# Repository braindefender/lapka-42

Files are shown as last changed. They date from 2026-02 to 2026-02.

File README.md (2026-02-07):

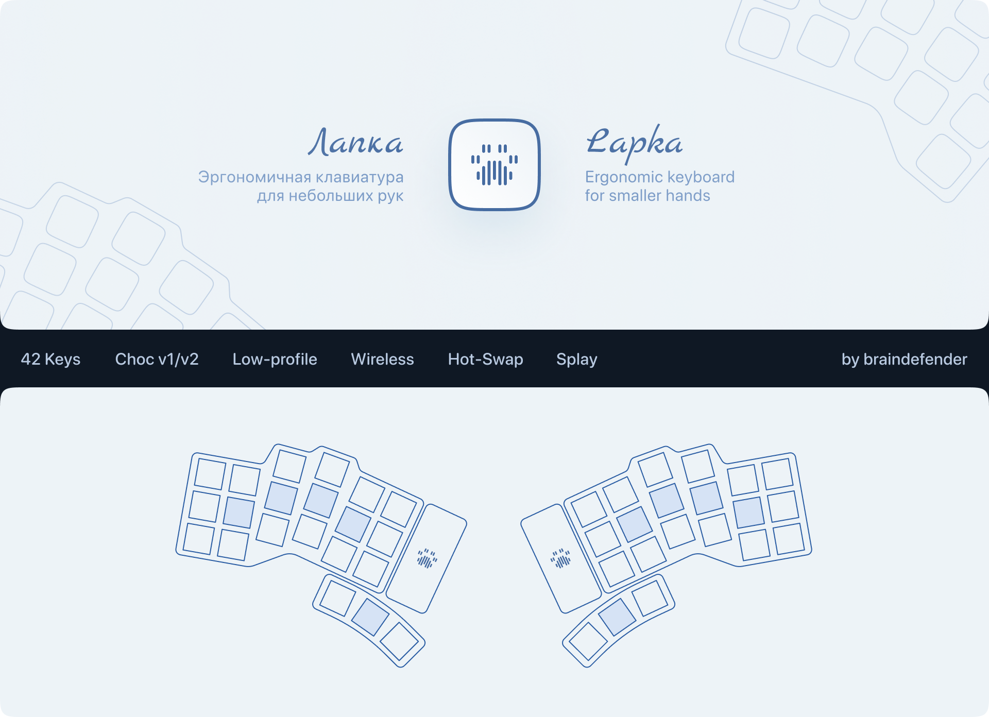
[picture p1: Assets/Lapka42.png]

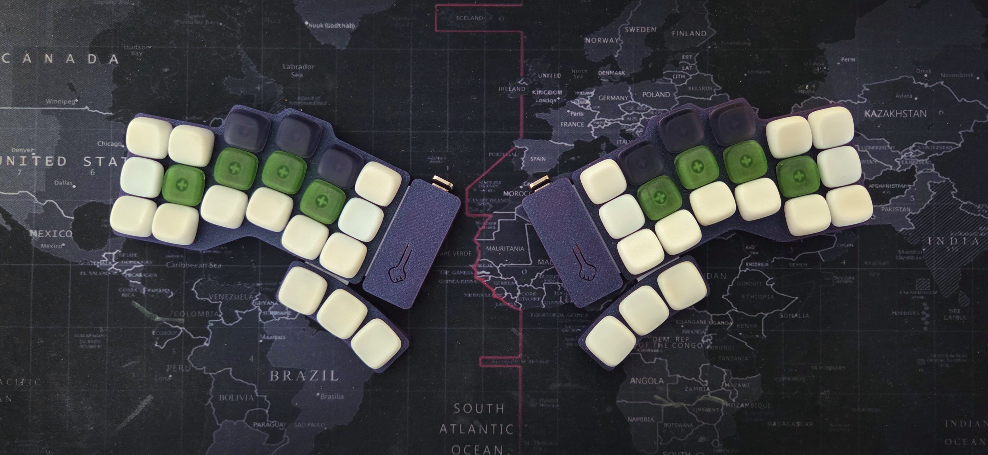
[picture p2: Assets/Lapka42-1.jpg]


[English version of this README](./README_EN.md)

# Лапка 42

Беспроводная эргономичная сплит-клавитура для тех, у кого лапки (:

**Информация:**

| | |
| :--- | :--- |
| **Количество клавиш** | 42 |
| **Тип матрицы** | Диодная |
| **Направление диодов**  | Col2Row |
| **Совместимые MCU** | nRF52840 (SuperMini, nice!nano) |
| **Совместимые АКБ** | 401230 |
| **Совместимые свитчи**  | Choc v1/v2 |
| **Свитч-спейсинг** | Choc (18×17mm) |
| **Расположение клавиш** | Splay |

**Структура репозитория:**

| Директория | Описание |
| ---: | :--- |
| 3MF | Проект OrcaSlicer (для примера параметров печати) |
| Assets | Изображения и фото |
| Build | Описание [процесса сборки](./Build/BUILD_GUIDE_RU.md) |
| Fusion | Проект Autodesk Fusion 360 |
| Gerbers | Gerber-файлы для производства плат |
| KiCad | Проект KiCad (схема, плата, компоненты) |
| STL | 3D-модели частей корпуса |

**Части корпуса:**
| Файл | Описание |
| -----: | :--- |
| Bottom | Нижняя часть корпуса, имеет вырезы под hotswap-сокеты и диоды |
|  Cover | Крышка для АКБ и кнопки Reset |
|  Frame | Верхняя часть корпуса, для тайп-кластера |
|  Thumb | Верхняя часть корпуса, для тамб-кластера |

**Разметка пинов:**

> C — колонки, R — строки, нумерация слева направо, сверху вниз

|  Пин  | Левая | Правая |
| :---: | :---: | :----: |
|  C0 |  D4 |  D10 |
|  C1 |  D5 |  D16 |
|  C2 |  D6 |  D14 |
|  C3 |  D7 |  D15 |
|  C4 |  D8 |  D18 |
|  C5 |  D9 |  D19 |
| | |
|  R0 |  D2 |  D21 |
|  R1 |  D3 |  D20 |
|  R2 |  D16  | D8 |
|  R3 |  D10  | D9 |

## Прошивка

- [`ZMK × Wellum`](https://github.com/braindefender/lapka-zmk-config/tree/lapka-42)
- `RMK × Wellum` — *в разработке*

## История изменений

### v1
- Первичный релиз.

## Фото

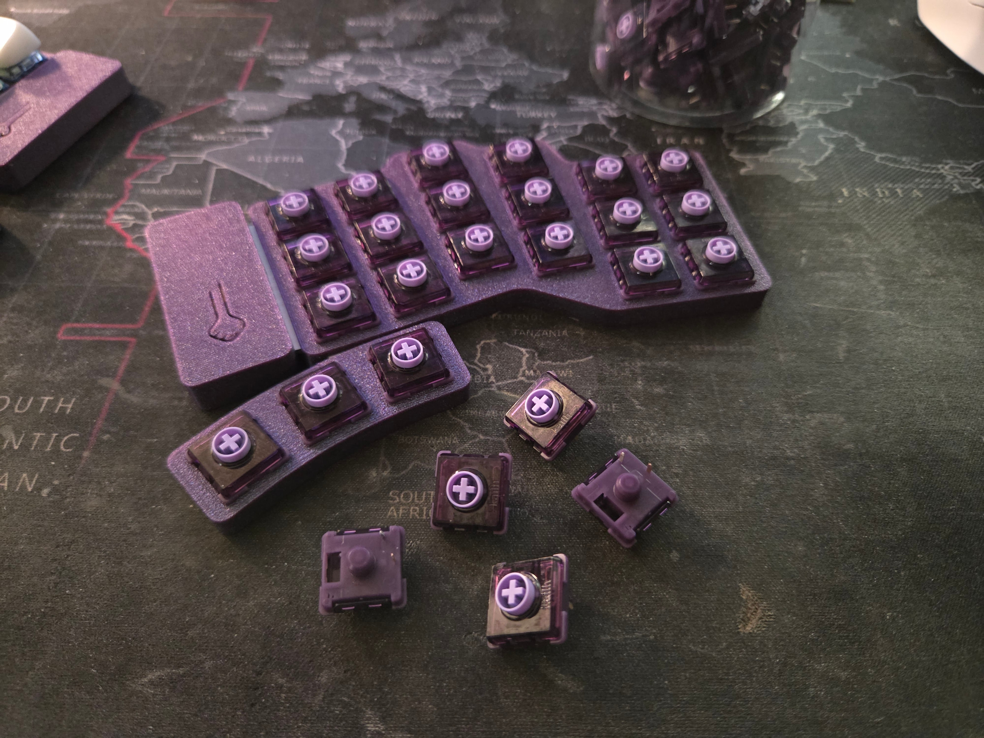
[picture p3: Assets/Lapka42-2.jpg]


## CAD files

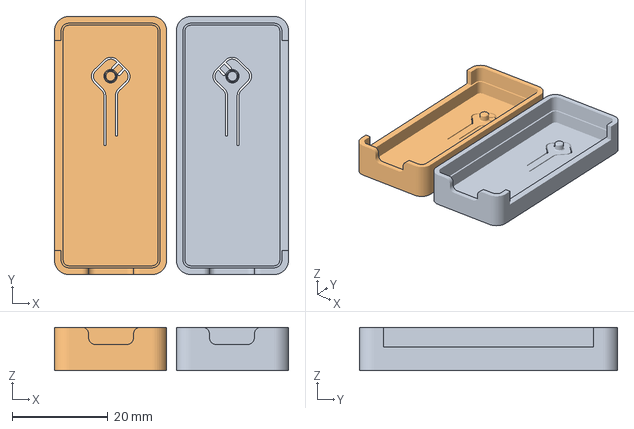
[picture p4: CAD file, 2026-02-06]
3MF/Cover.3mf
49.0 x 54.0 x 9.10 mm
Cover.stl x 2

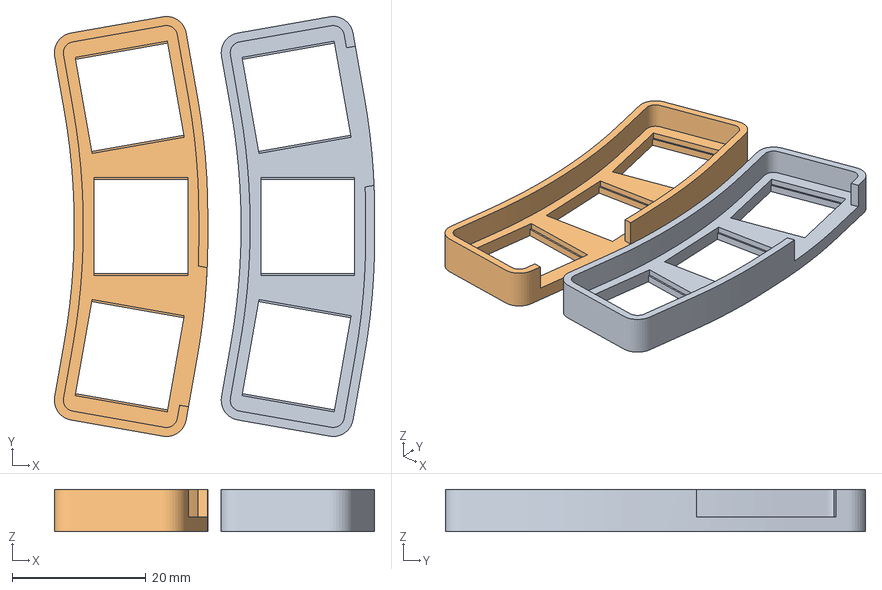
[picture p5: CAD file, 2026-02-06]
3MF/Thumb.3mf
47.9 x 62.9 x 6.30 mm
Thumb.stl x 2

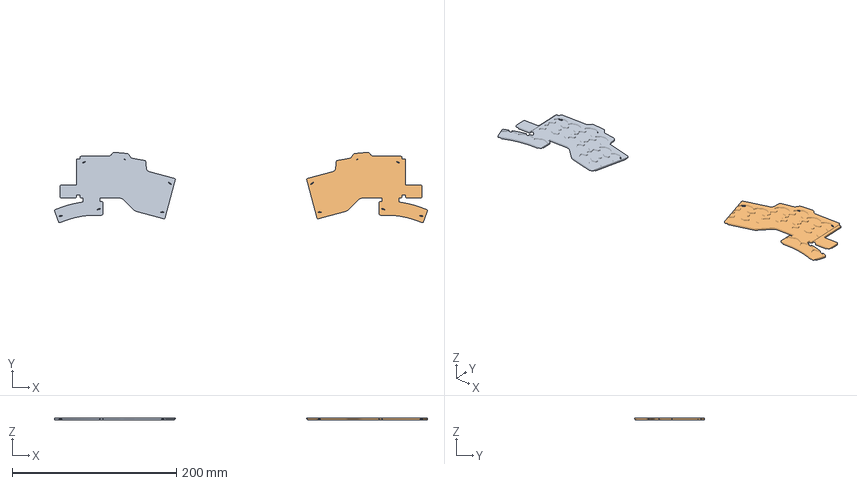
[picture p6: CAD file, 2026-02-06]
3MF/Bottom.3mf
454.4 x 85.7 x 2.30 mm
Bottom.stl x 2

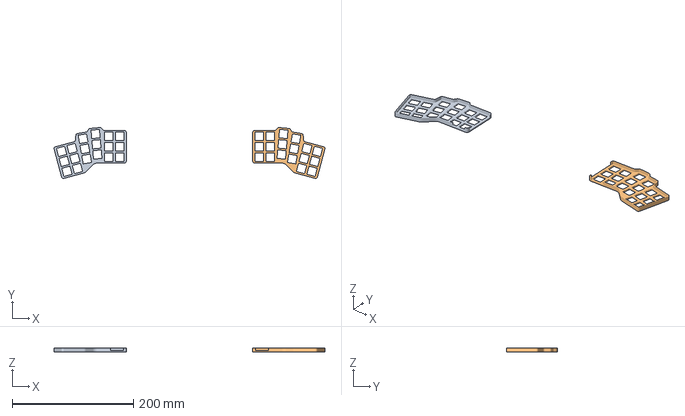
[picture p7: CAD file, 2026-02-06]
3MF/Frame.3mf
447.2 x 84.1 x 6.30 mm
Frame.stl x 2

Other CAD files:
STL/Bottom.stl
STL/Cover.stl
STL/Frame.stl
STL/Thumb.stl

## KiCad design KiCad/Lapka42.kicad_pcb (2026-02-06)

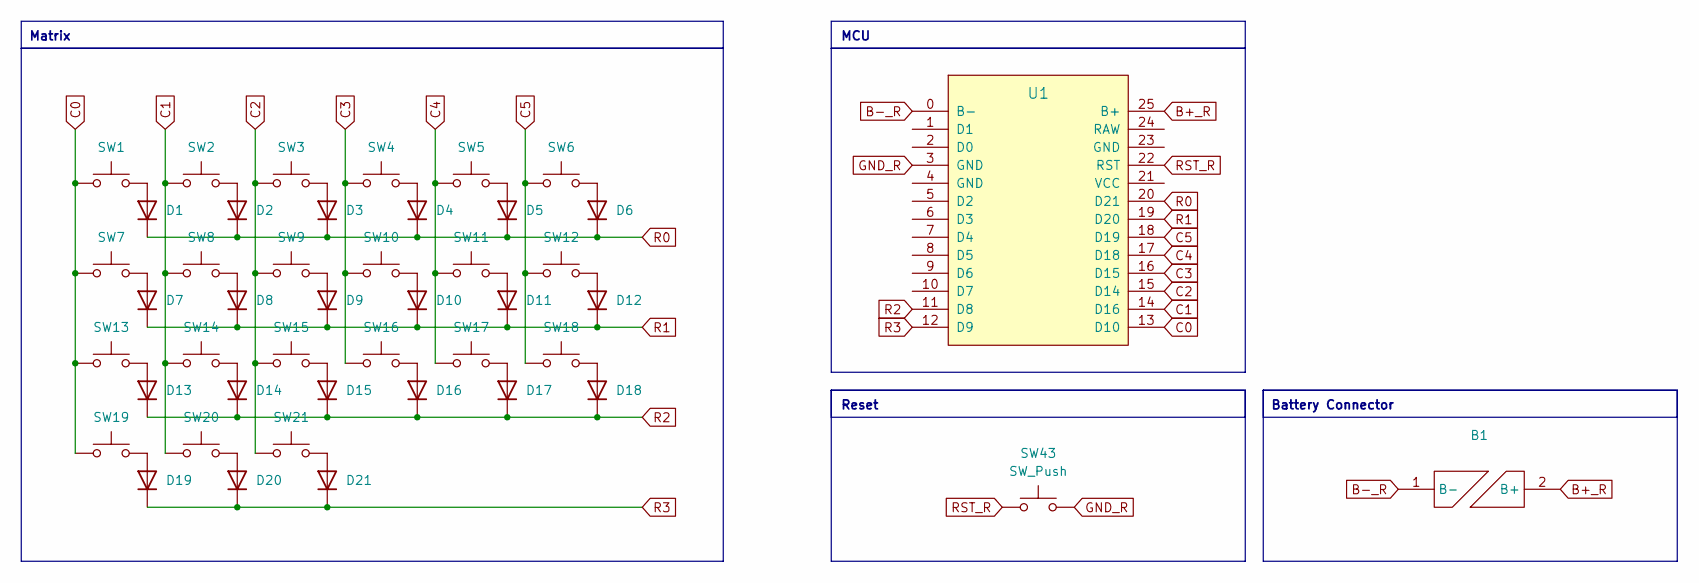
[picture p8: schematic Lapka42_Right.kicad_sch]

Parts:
B1: BAT_RECT
D1, D2, D3, D4, D5, D6, D7, D8, D9, D10, D11, D12, D13, D14, D15, D16, D17, D18, D19, D20, D21: D_SOD-323_Increased
SW1, SW2, SW3, SW4, SW5, SW6, SW7, SW8, SW9, SW10, SW11, SW12, SW13, SW14, SW15, SW16, SW17, SW18, SW19, SW20, SW21: SW_Choc_V1V2_HS
SW43: SW_Push; SW_SMD_5x5
U1: U_ProMicro_nRF52840_MidMount

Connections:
B+_R: B1.2 (B+), U1.25 (B+)
B-_R: B1.1 (B-), U1.0 (B-)
C0: SW1.1, SW7.1, SW13.1, SW19.1, U1.13 (D10)
C1: SW2.1, SW8.1, SW14.1, SW20.1, U1.14 (D16)
C2: SW3.1, SW9.1, SW15.1, SW21.1, U1.15 (D14)
C3: SW4.1, SW10.1, SW16.1, U1.16 (D15)
C4: SW5.1, SW11.1, SW17.1, U1.17 (D18)
C5: SW6.1, SW12.1, SW18.1, U1.18 (D19)
GND_R: SW43.2, U1.3 (GND)
unnamed: D1.2 (A), SW1.2
unnamed: D2.2 (A), SW2.2
unnamed: D3.2 (A), SW3.2
unnamed: D4.2 (A), SW4.2
unnamed: D5.2 (A), SW5.2
unnamed: D6.2 (A), SW6.2
unnamed: D7.2 (A), SW7.2
unnamed: D8.2 (A), SW8.2
unnamed: D9.2 (A), SW9.2
unnamed: D10.2 (A), SW10.2
unnamed: D11.2 (A), SW11.2
unnamed: D12.2 (A), SW12.2
unnamed: D13.2 (A), SW13.2
unnamed: D14.2 (A), SW14.2
unnamed: D15.2 (A), SW15.2
unnamed: D16.2 (A), SW16.2
unnamed: D17.2 (A), SW17.2
unnamed: D18.2 (A), SW18.2
unnamed: D19.2 (A), SW19.2
unnamed: D20.2 (A), SW20.2
unnamed: D21.2 (A), SW21.2
R0: D1.1 (K), D2.1 (K), D3.1 (K), D4.1 (K), D5.1 (K), D6.1 (K), U1.20 (D21)
R1: D7.1 (K), D8.1 (K), D9.1 (K), D10.1 (K), D11.1 (K), D12.1 (K), U1.19 (D20)
R2: D13.1 (K), D14.1 (K), D15.1 (K), D16.1 (K), D17.1 (K), D18.1 (K), U1.11 (D8)
R3: D19.1 (K), D20.1 (K), D21.1 (K), U1.12 (D9)
RST_R: SW43.1, U1.22 (RST)

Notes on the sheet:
Battery Connector
MCU
Matrix
Reset

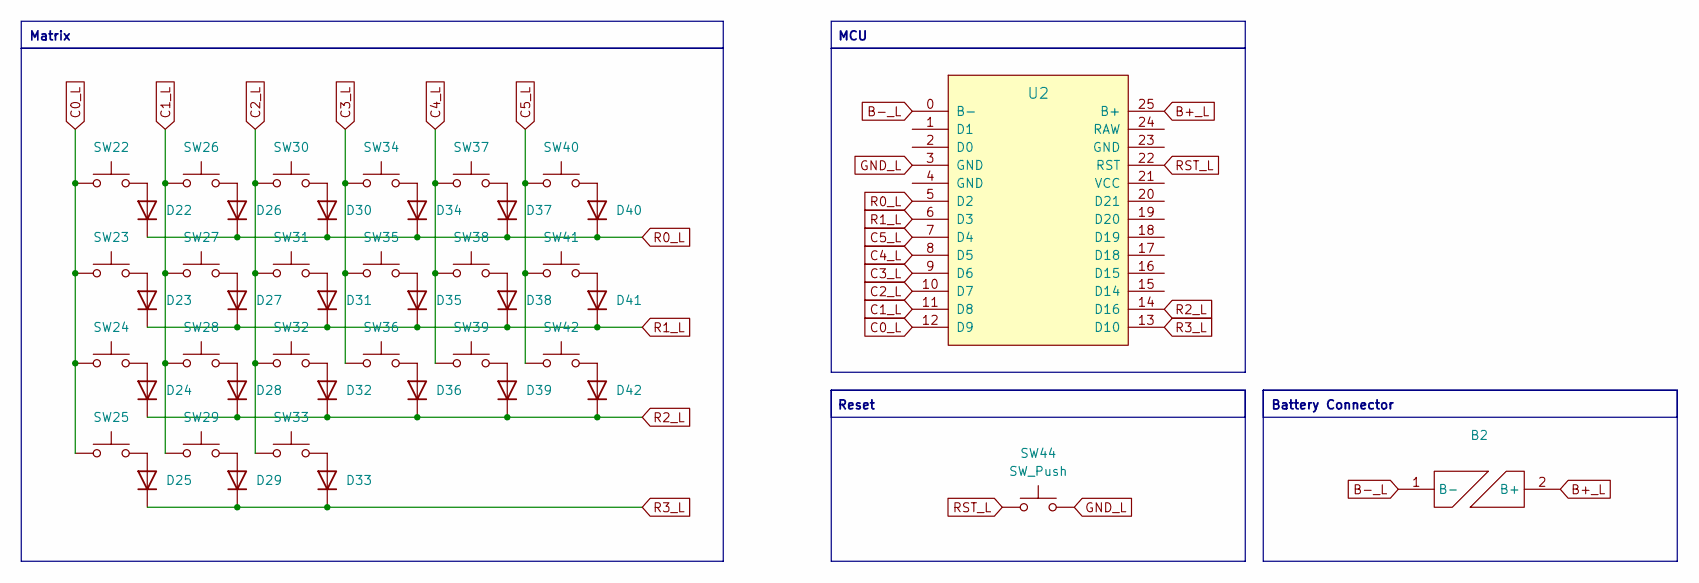
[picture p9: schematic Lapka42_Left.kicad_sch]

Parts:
B2: BAT_RECT
D22, D23, D24, D25, D26, D27, D28, D29, D30, D31, D32, D33, D34, D35, D36, D37, D38, D39, D40, D41, D42: D_SOD-323_Increased
SW22, SW23, SW24, SW25, SW26, SW27, SW28, SW29, SW30, SW31, SW32, SW33, SW34, SW35, SW36, SW37, SW38, SW39, SW40, SW41, SW42: SW_Choc_V1V2_HS
SW44: SW_Push; SW_SMD_5x5
U2: U_ProMicro_nRF52840_MidMount

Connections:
B+_L: B2.2 (B+), U2.25 (B+)
B-_L: B2.1 (B-), U2.0 (B-)
C0_L: SW22.1, SW23.1, SW24.1, SW25.1, U2.12 (D9)
C1_L: SW26.1, SW27.1, SW28.1, SW29.1, U2.11 (D8)
C2_L: SW30.1, SW31.1, SW32.1, SW33.1, U2.10 (D7)
C3_L: SW34.1, SW35.1, SW36.1, U2.9 (D6)
C4_L: SW37.1, SW38.1, SW39.1, U2.8 (D5)
C5_L: SW40.1, SW41.1, SW42.1, U2.7 (D4)
GND_L: SW44.2, U2.3 (GND)
unnamed: D22.2 (A), SW22.2
unnamed: D23.2 (A), SW23.2
unnamed: D24.2 (A), SW24.2
unnamed: D25.2 (A), SW25.2
unnamed: D26.2 (A), SW26.2
unnamed: D27.2 (A), SW27.2
unnamed: D28.2 (A), SW28.2
unnamed: D29.2 (A), SW29.2
unnamed: D30.2 (A), SW30.2
unnamed: D31.2 (A), SW31.2
unnamed: D32.2 (A), SW32.2
unnamed: D33.2 (A), SW33.2
unnamed: D34.2 (A), SW34.2
unnamed: D35.2 (A), SW35.2
unnamed: D36.2 (A), SW36.2
unnamed: D37.2 (A), SW37.2
unnamed: D38.2 (A), SW38.2
unnamed: D39.2 (A), SW39.2
unnamed: D40.2 (A), SW40.2
unnamed: D41.2 (A), SW41.2
unnamed: D42.2 (A), SW42.2
R0_L: D22.1 (K), D26.1 (K), D30.1 (K), D34.1 (K), D37.1 (K), D40.1 (K), U2.5 (D2)
R1_L: D23.1 (K), D27.1 (K), D31.1 (K), D35.1 (K), D38.1 (K), D41.1 (K), U2.6 (D3)
R2_L: D24.1 (K), D28.1 (K), D32.1 (K), D36.1 (K), D39.1 (K), D42.1 (K), U2.14 (D16)
R3_L: D25.1 (K), D29.1 (K), D33.1 (K), U2.13 (D10)
RST_L: SW44.1, U2.22 (RST)

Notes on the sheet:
Reset
Matrix
Battery Connector
MCU

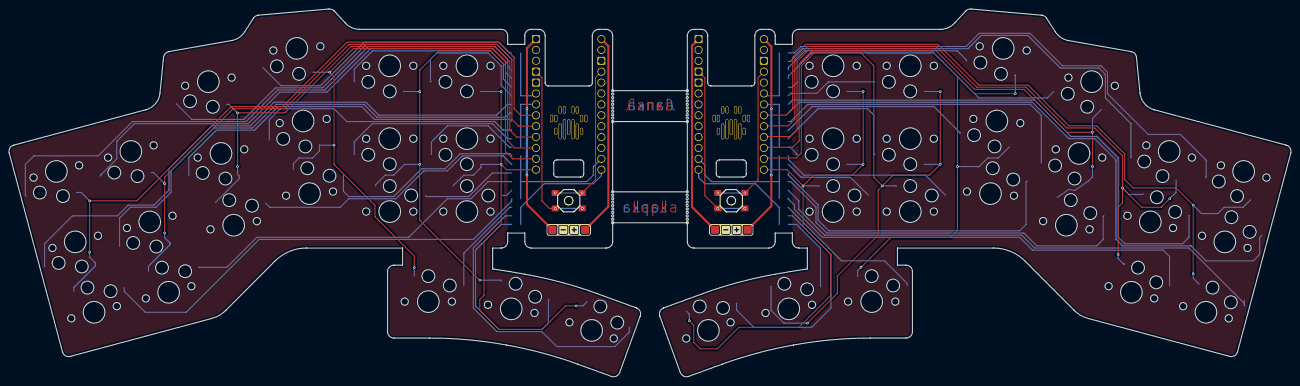
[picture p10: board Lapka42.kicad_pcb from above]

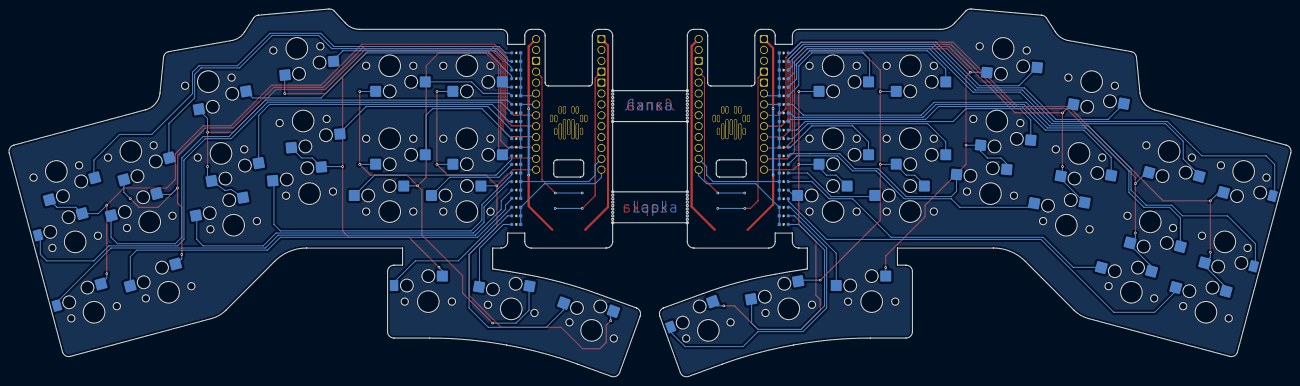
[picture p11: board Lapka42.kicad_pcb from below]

Board: 2 copper layers, 299.0 x 85.8 mm, 90 parts (42 on the bottom side), 70 nets.

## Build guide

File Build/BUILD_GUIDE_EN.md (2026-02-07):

# Build guide

## List of required parts

| Part | Amount | Description | Link |
| --- | --- | --- | --- |
| PCB | 2 | Main PCB board | |
| MCU | 2 | nRF52840 MCU | [Link](#nrf52840-mcu) |
| Battery | 2 | 401230 Size, 120-150mAh | [Link](#401230-battery) |
| Tactile button  | 2 | 4x4x1.5mm button | [Link](#tactile-button) |
| SMD Diode | 42 | 1N4148 (SOD-323) | [Link](#1n4148-sod-323-diode) |
| Hot-Swap socket | 42 | Kailh PG1350 | [Link](#kailh-pg1350-hot-swap-socket) |
| Switches | 42 | Kailh Choc v1 / v2 | [Link](#kailh-choc-v1--v2) |
| Keycaps | 42 | Choc-Spacing | [Link](#choc-spacing-keycaps) |
| Pin Header | 9×2×2  | (Optional) | [Link](#hot-swap-pin-header) |
| Rubber feet | 16 | 8x2mm | [Link](#rubber-feet) |

| Name | Amount | Description |
| --- | --- | --- |
| `Frame_Main`  | 2 | Type-cluster case |
| `Frame_Thumb` | 2 | Thumb-cluster case |
| `Cover` | 2 | Battery/Reset cover |
| `Bottom` | 2 | Bottom part of the case |

## Parts Links

### 401230 Battery
You can buy these in most places. These batteries are widely used in portable devices.
Don't be fooled by the large declared capacity (200-250+), often it's only 120-150mAh.

- [OZON | MyDigitals](https://www.ozon.ru/product/akkumulyator-batareya-401230-120mah-3-7v-30h12h4-mm-1812801020/)
- [AliExpress | EasyLander](https://aliexpress.ru/item/1005006119986947.html?sku_id=12000048850576528)

### nRF52840 MCU
> Notice the USB-C connector [difference](#mcu-usb-c-difference)

- [AliExpress | TENSTAR Store](https://aliexpress.ru/item/1005006282506884.html)
- [AliExpress | Simple Robot Store](https://aliexpress.ru/item/1005008896713501.html)

### Hot-Swap Pin Header
This is completely optional. You can solder MCU to PCB with those that come with MCU.
However, using Hot-Swap Pin Headers is more convinient even if you won't use hot-swap.

- [AliExpress | EQV Official Store](https://aliexpress.ru/item/1005007465756012.html)

### 1N4148 SOD-323 Diode
- [AliExpress | TZT teng Official Store](https://aliexpress.ru/item/1005008443360532.html)

### Tactile Button
- [AliExpress | LOSUYINE Store](https://aliexpress.ru/item/32815925814.html)
- [AliExpress | KRYOND Electronic Store](https://aliexpress.ru/item/1005009981759314.html)

### Rubber Feet
- [AliExpress | Meifang Store](https://aliexpress.ru/item/1005005315398342.html)

### Kailh PG1350 Hot-Swap Socket
- [AliExpress | Dafu Store](https://aliexpress.ru/item/1005009449387695.html)
- [AliExpress | KBDiy Switch Store](https://aliexpress.ru/item/1005004916925259.html)

### Kailh Choc v1 / v2
I highly recommend checking out [Watchman's Switch Database](https://aroum.github.io)

### Choc-Spacing Keycaps
> Currently, there are almost no keycaps for Choc v2 with Choc spacing on the market. Of the open-source options, I can only suggest [KLP Lamé](https://github.com/braindefender/KLP-Lame-Keycaps).

- [GitHub | KLP Lamé](https://github.com/braindefender/KLP-Lame-Keycaps)
- [GitHub | GammaCaps](https://github.com/sqdbruh/gammacaps)
- [BeeKeeb | Tai-Hao THCS](https://showcase.beekeeb.com/choc-spaced-chocv2-keycaps/)

## Guide

1. Make sure you have all the necessary parts for assembly, as well as a soldering iron, solder paste, or solder wire (soldering paste will be much easier).

2. Separate the boards from the shipping connectors. This can be done by gently breaking them off, holding them with your fingers near the break seam.

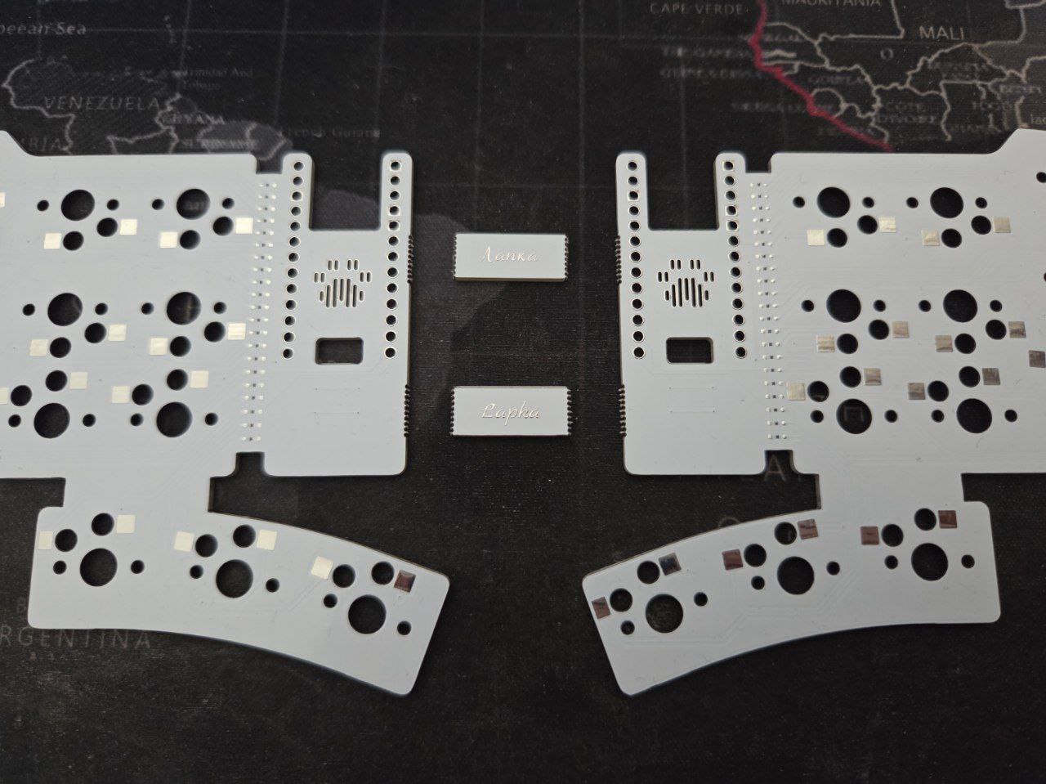
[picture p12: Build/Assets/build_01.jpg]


3. Apply solder paste to the hotswap socket pads and solder the sockets. The socket should be positioned so that the larger part faces out to the side and the smaller part faces the center.

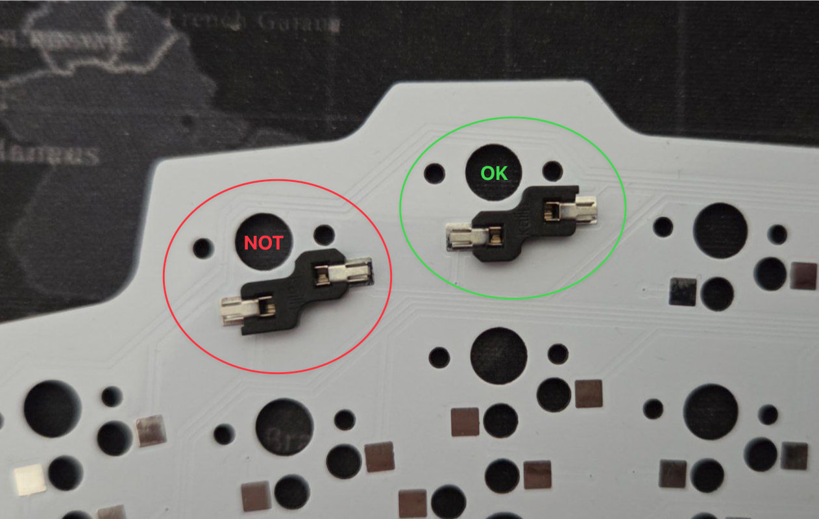
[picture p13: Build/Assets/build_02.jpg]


> I usually apply solder paste to all the socket pads, then install the sockets and solder one right pin of each socket (from right to left) first, holding the socket with my finger. After that, I rotate the board 180° and repeat the same process for the left pin of the socket. This allows me to solder all the sockets quickly and without misalignment.

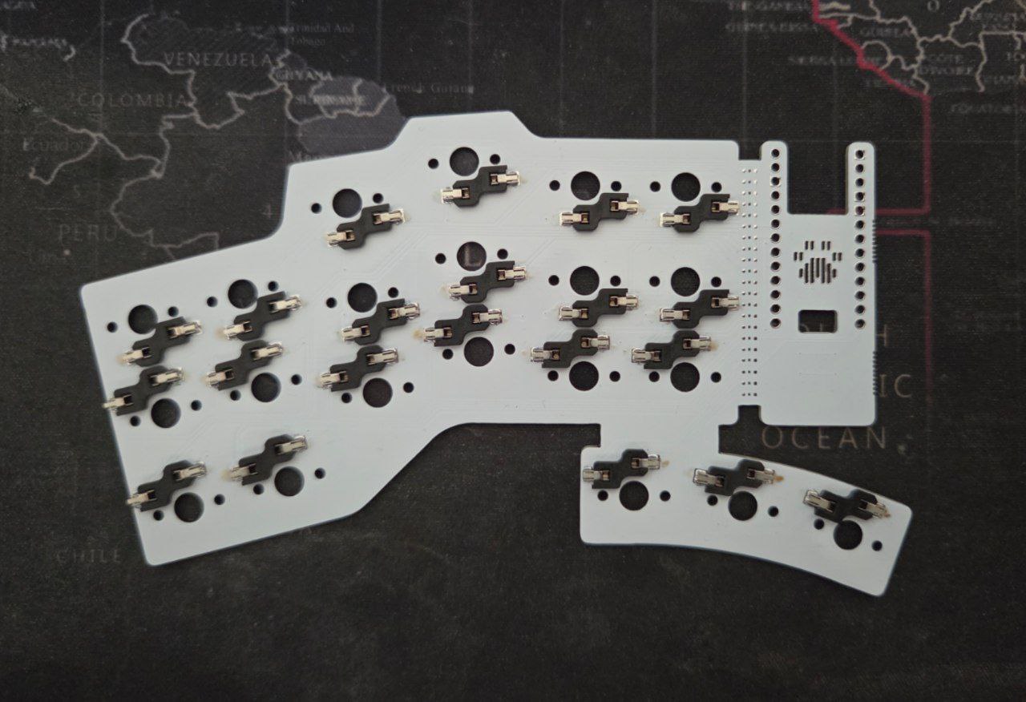
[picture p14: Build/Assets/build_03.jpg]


4. Apply solder paste to the pads for the SMD diodes and solder the diodes themselves. The diodes should be positioned according to the [markings](#1n4148w-t4-diode-markings). Two stripes on the diode body indicate the position of the **cathode** — so we position the diodes so that these two stripes face the controller.

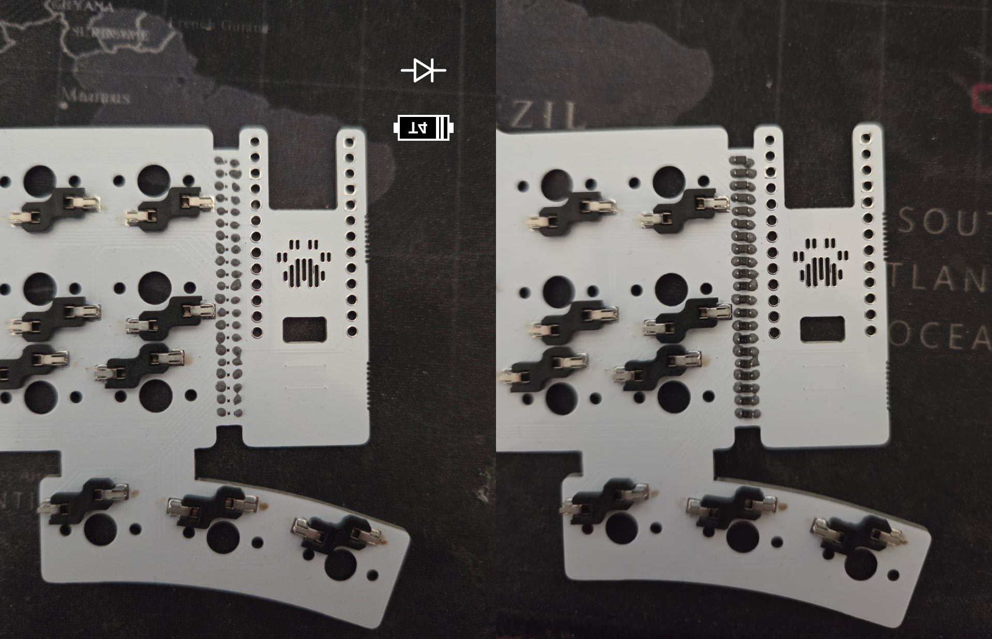
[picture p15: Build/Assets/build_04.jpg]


5. Prepare the pin headers. To measure how much to break it, push the pins into the holes on either side of the board. You should have exactly 9 pins. We'll need two of these pieces.

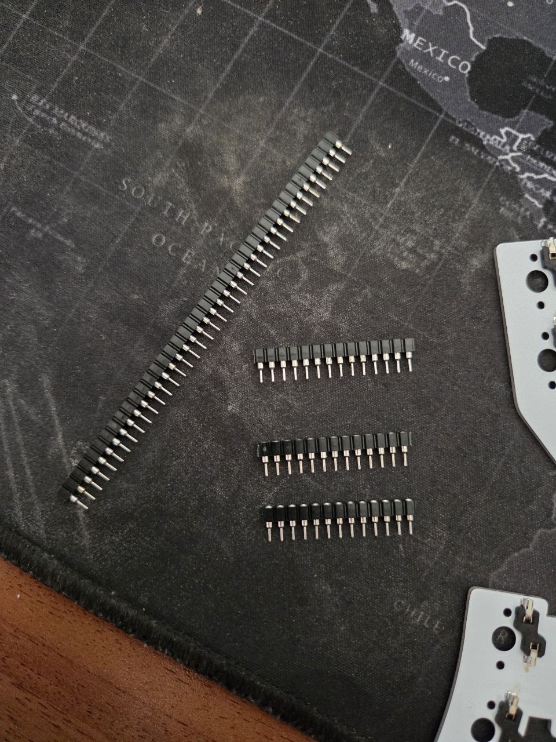
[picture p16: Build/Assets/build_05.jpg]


6. Apply solder paste to the pin header holes and install the pin header in the holes so that the plastic part is on the opposite side from the diodes/sockets. You can solder the outer pins to keep it in place. During soldering, any solder paste remaining on the pins will naturally move down to the pad.

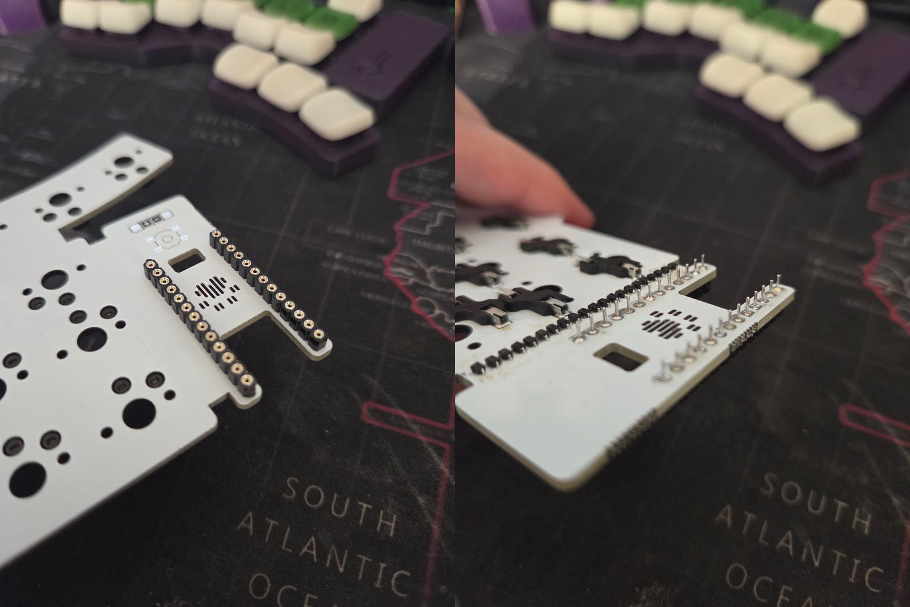
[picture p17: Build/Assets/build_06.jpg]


7. After the hotswap sockets, diodes, and pin headers have been soldered, thoroughly clean the board of flux. I do this with isopropyl alcohol, wiping the pads with a toothbrush or a stiff brush. After cleaning, leave the board in a warm place to allow all the alcohol or water to dry. While one board is drying, you can begin soldering the other half.

8. Make sure the nRF52840 controllers are working properly. To do this, you can flash a [test firmware](https://github.com/braindefender/lapka-zmk-config/tree/lapka-42-test), short the row and column contacts in pairs, and observe how the keys are pressed using [key-test](https://key-test.ru). Or, you can skip this step at your own risk. However, desoldering a faulty controller is the last thing you want to do, so it's better to be safe than sorry.

9. Install the nRF52840 controller on the pins with the SMD components facing the board. There are cutouts on the board for the antenna, USB Type-C connector, and a couple of (transistors?). After installing the controller, apply solder paste to the contacts and solder it. Be careful to hold the controller level when soldering, otherwise one side will stick out beyond the case.

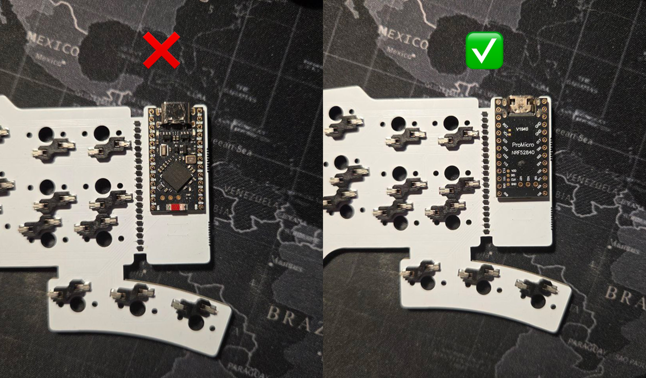
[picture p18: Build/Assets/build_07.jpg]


10. Apply solder paste to the tactile button and battery pads and solder them in place. The black wire is the minus, and the red wire is plus. The tactile button also has polarity — position it horizontally.

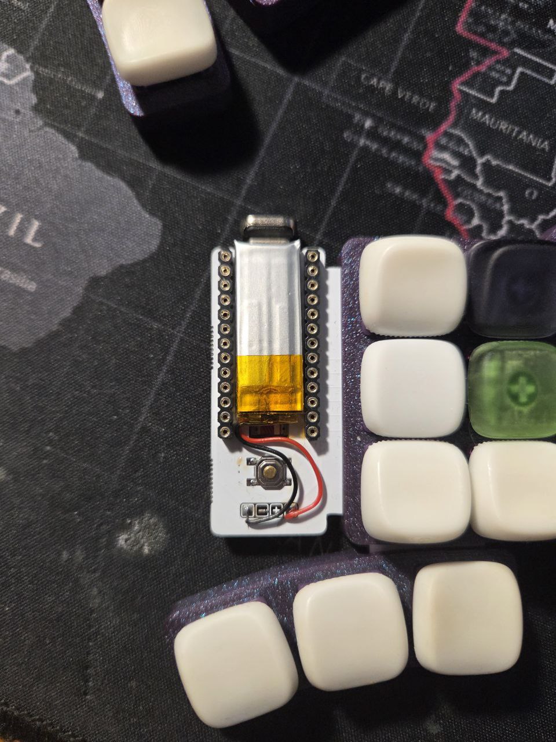
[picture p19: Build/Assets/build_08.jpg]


11. Once all the components are soldered, you can install the case parts and insert the switches into the sockets. Done! Now you can [flash the keyboard](../README_EN.md#firmware) and use it.

## Notes

### MCU USB-C Difference

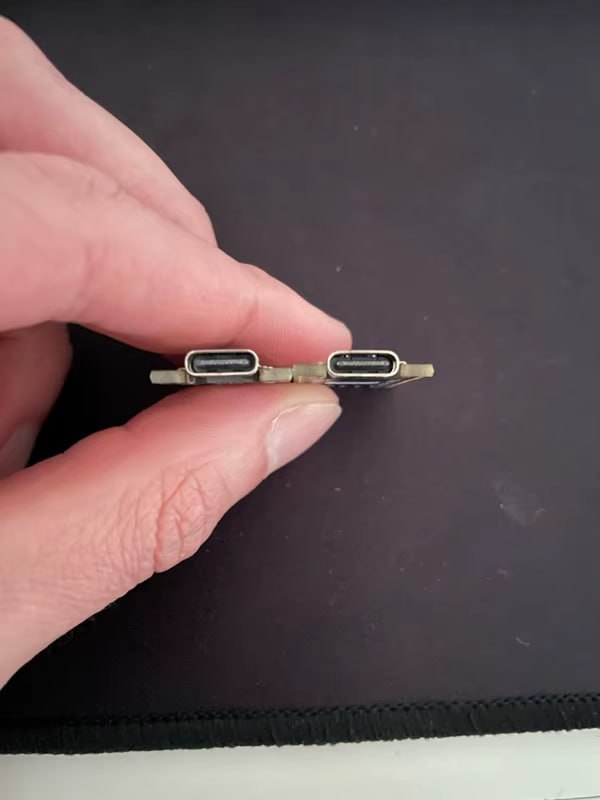
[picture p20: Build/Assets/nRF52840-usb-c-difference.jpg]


[nRF52840](https://github.com/joric/nrfmicro/wiki/Alternatives#supermini-nrf52840) is sold in several variants, among which there is a difference in the USB Type-C connector. For example, boards from Simple Robot Store have an extended USB-C port, while most boards from other vendors/manufacturers have a standard USB-C port. The MCU enclosure supports both types.

### 1N4148W (T4) Diode markings

Cathode is marked with one or several stripes on the diode body.

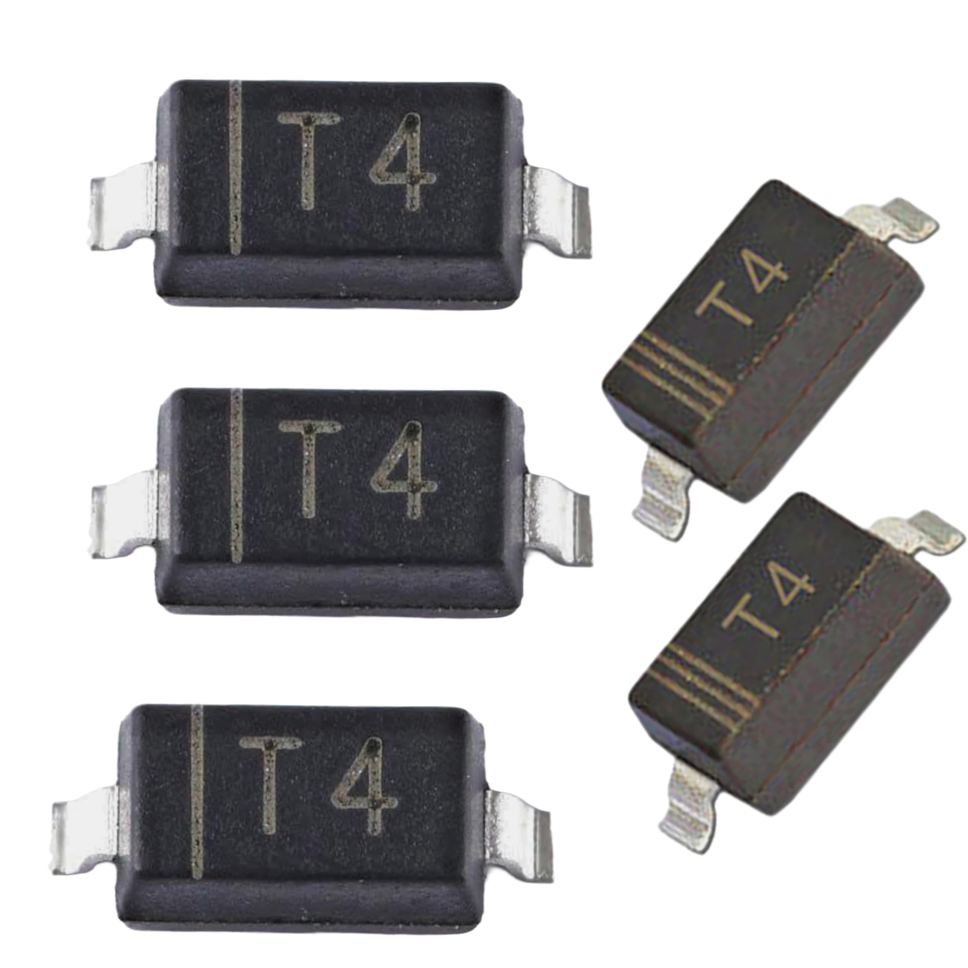
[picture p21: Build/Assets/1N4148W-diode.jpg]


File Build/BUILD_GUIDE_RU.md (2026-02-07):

# Инструкция по сборке

## Список необходимых деталей

| Деталь | Кол-во | Описание | Ссылка |
| --- | --- | --- | --- |
| PCB | 2 | Основная плата | |
| MCU | 2 | Контроллер nRF52840 | [Ссылка](#nrf52840-mcu) |
| Батарея | 2 | Размер 401230, 120-150mAh | [Ссылка](#401230-battery) |
| Тактовая кнопка | 2 | 4x4x1.5mm button | [Ссылка](#tactile-button) |
| SMD Диоды | 42 | 1N4148 (SOD-323) | [Ссылка](#1n4148-sod-323-diode) |
| Hot-Swap сокеты | 42 | Kailh PG1350 | [Ссылка](#kailh-pg1350-hot-swap-socket) |
| Свитчи | 42 | Kailh Choc v1 / v2 | [Ссылка](#kailh-choc-v1--v2) |
| Кейкапы | 42 | Choc-Spacing | [Ссылка](#choc-spacing-keycaps) |
| Гребёнка | 9×2×2  | (Опционально) | [Ссылка](#hot-swap-pin-header) |
| Силиконовые бамперы | 16 | 8x2mm | [Ссылка](#силиконовые-бамперы) |

| Название | Кол-во | Описание |
| --- | --- | --- |
| `Frame_Main`  | 2 | Корпус для тайп-кластера  |
| `Frame_Thumb` | 2 | Корпус для тамб-кластера  |
| `Cover` | 2 | Крышка для батареи/ресета |
| `Bottom` | 2 | Нижняя часть корпуса |

## Ссылки на детали

### 401230 Battery
Можно купить практически где угодно. На OZON их куча. Такие АКБ стоят в видео-регистраторах.
Не ведитесь на большую заявленную ёмкость (200-250+), зачастую там всего 120-150mAh.

- [OZON | MyDigitals](https://www.ozon.ru/product/akkumulyator-batareya-401230-120mah-3-7v-30h12h4-mm-1812801020/)
- [AliExpress | EasyLander](https://aliexpress.ru/item/1005006119986947.html?sku_id=12000048850576528)

### nRF52840 MCU
> Стоит обратить внимание на [отличия коннектора USB-C](#разница-mcu-usb-c)

- [AliExpress | TENSTAR Store](https://aliexpress.ru/item/1005006282506884.html)
- [AliExpress | Simple Robot Store](https://aliexpress.ru/item/1005008896713501.html)

### Hot-Swap Pin Header
Это полностью опционально. Вы можете припаять контроллер к плате с помощью комплектной гребёнки.
Однако hot-swap гребёнку паять будет удобнее, даже если вы не планируете использовать hot-swap.

- [AliExpress | EQV Official Store](https://aliexpress.ru/item/1005007465756012.html)

### 1N4148 SOD-323 Diode
- [AliExpress | TZT teng Official Store](https://aliexpress.ru/item/1005008443360532.html)

### Tactile Button
- [AliExpress | LOSUYINE Store](https://aliexpress.ru/item/32815925814.html)
- [AliExpress | KRYOND Electronic Store](https://aliexpress.ru/item/1005009981759314.html)

### Силиконовые бамперы
- [AliExpress | Meifang Store](https://aliexpress.ru/item/1005005315398342.html)

### Kailh PG1350 Hot-Swap Socket
- [AliExpress | Dafu Store](https://aliexpress.ru/item/1005009449387695.html)
- [AliExpress | KBDiy Switch Store](https://aliexpress.ru/item/1005004916925259.html)

### Kailh Choc v1 / v2
Настоятельно рекомендую изучить [базу свитчей от Watchman'а](https://aroum.github.io)

### Choc-Spacing Keycaps
> На данный момент, на рынке очень мало кейкапов для Choc v2 с Choc-спейсингом. Из open-source вариантов, я могу предложить только [KLP Lamé](https://github.com/braindefender/KLP-Lame-Keycaps).

- [GitHub | KLP Lamé](https://github.com/braindefender/KLP-Lame-Keycaps)
- [GitHub | GammaCaps](https://github.com/sqdbruh/gammacaps)
- [BeeKeeb | Tai-Hao THCS](https://showcase.beekeeb.com/choc-spaced-chocv2-keycaps/)

## Инструкция

1. Проверьте, что у вас имеются все необходимые детали для сборки, а также паяльник, паяльная паста или припой (с паяльной пастой будет значительно удобнее).

2. Отделите платы от транспортировочных перемычек. Это можно сделать просто аккуратно отломив их, придерживая пальцами недалеко от места излома.



3. Нанесите паяльную пасту на площадки для hotswap-сокетов и припаяйте сами сокеты. Сокет нужно располагать так, чтобы его большая часть смотрела в сторону, а маленькая в центр.



> Обычно, я наношу пасту на все площадки сокетов, затем устанавливаю сокеты и сначала припаиваю по одному правому пину каждого сокета (справа налево), придерживая пальцем сокет. После чего, поворачиваю плату на 180° и повторяю тот же процесс для левого пина сокета. Так получается достаточно быстро и без смещения припаять все сокеты.



4. Нанесите паяльную пасту на площадки для SMD-диодов и припаяйте сами диоды. Диоды нужно располагать в соответствии с [маркировкой](#маркировка-диодов-1n4148w-t4). Две полоски на корпусе диода означают положение **катода** — поэтому располагаем диоды так, чтобы эти две полоски смотрели в сторону контроллера.



5. Подготовьте гребёнку. Чтобы отмерить то, как её нужно надломить, просуньте пины в отверстия с любой стороны платы. Должно получиться ровно 9 пинов. Нам понадобится два таких отрезка.



6. Нанесите паяльную пасту в отверстия для гребёнки, установите гребёнку в отверстия так, чтобы пластиковая часть находилась с противоположной стороны от диодов/сокетов. Можно припаять крайние пины, чтобы она оставалась в закреплённом положении. В процессе пайки, паста, оставшаяся на штырьках, сама спустится на площадку.



7. После того, как были припаяны hotswap-сокеты, диоды и гребёнка, плату нужно тщательно отмыть от флюса. Я делаю это с помощью изопропилового спирта, протирая площадки зубной щёткой или жёсткой кисточкой. После мойки оставляем плату в тёплом месте, чтобы весь спирт или вода высохли. Пока одна плата сушится, можно приступать к пайке второй половинки.

8. Убедитесь, что контроллеры nRF52840 работают исправно. Для этого можете прошить в них [тестовую прошивку](https://github.com/braindefender/lapka-zmk-config/tree/lapka-42-test), попарно замыкать контакты строк и столбцов и смотреть как в [key-test](https://key-test.ru) нажимаются клавиши. Либо, можете на свой страх и риск пропустить этот пункт. Но выпаивать неисправный контроллер — последнее, что хотелось бы делать, поэтому, лучше «перебздеть».

9. Установите контроллер nRF52840 на штырьки так, чтобы SMD-компоненты смотрели в сторону платы. Для антенны, USB Type-C коннектора и пары (транзисторов?) в плате предусмотрены вырезы. После установки контроллера, нанесите паяльную пасту на контакты и припаяйте его. Будьте аккуратны, контроллер при пайке нужно держать ровно, иначе он будет выпирать одной из своих сторон за корпус.



10. Нанесите паяльную пасту на площадки для тактовой кнопки и батареи и припаяйте эти элементы. Чёрный провод — это «минус», красный — это «плюс». Тактовая кнопка тоже имеет «полярность», располагайте её горизонтально.



11. После того, как все элементы припаяны, можно установить части корпуса и вставить свитчи в сокеты. Готово. Теперь можно [прошить](https://github.com/braindefender/lapka-zmk-config/tree/lapka-42) клавиатуру и пользоваться ей.

## Заметки

### Разница MCU USB-C



[nRF52840](https://github.com/joric/nrfmicro/wiki/Alternatives#supermini-nrf52840) продаётся в нескольких вариантах, среди которых есть отличие в USB Type-C коннекторе. Например, платы из Simple Robot Store имеют завышенный USB-C, в то время как большинство плат от других продавцов/производителей — обычные. Корпус для MCU поддерживает и тот, и другой тип.

### Маркировка диодов 1N4148W (T4)

Одной или несколькими полосками на корпусе диода отмечен катод.



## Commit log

2026-02-06 major: initial release
    [Bottom.3mf, Bottom.stl, Cover.3mf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]
2026-02-07 fix: add mcu, reset and battery placement photos
